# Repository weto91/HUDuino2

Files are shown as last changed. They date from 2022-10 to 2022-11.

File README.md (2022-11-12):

This project is under development. at this point everything is working, but there are some design issues that needs to be fixed. You can see the next steps below.

------------

### Next steps:
 - [ ] Add video of operation in README.md.
 - [ ] Redesign the shell to better fit any full-face helmet
 - [ ] Fix the problems that arise in the code.
 - [ ] Modify the wiring diagram to use the development board wemos d1 mini instead of nodemcu ESP12

------------

##  Description
HUDuino is an implementation of a HUD for bikers. This HUD will allows the biker to visualize the speed at which they are driving, the temperature inside the helmet, as well as the humidity, and they will be able to see if any notifications arrive on the phone while they are driving. 
This project seeks to improve the safety of bikers, avoiding distractions by lowering the head or handling the phone. 
Here you will find all the necessary resources to: 
 
 - View or modify the source code of the Android application
  - View, modify and upload to the development board the code necessary to make it work 
  - Make the electronic connections on the development board. 
  - Build the case for all the hardware with a 3D printer.

This project has three parts:
 - Android application
 - Arduino Sketch
 - Hardware construction

##  Android application 
The application will obtain several telemetries (described below) and send them via bluetooth to the Arduino device. It will also receive temperature and humidity data from the Arduino device.
The telemetry obtained by the application are:
- GPS Speed (Using Google API)
- Notifications received on the phone (It will only show that you have a notification from a specific application) The applications considered for notifications are the following:
   - WhatsApp
   - Facebook (and Facebook Messenger)
   - Instagram
   - Incoming calls (Considers the official android and samsung call application. Other applications of other brands are not contemplated, below it will be described how to add them)
   - The rest of the notifications will be ignored (Although they can be shown by modifying a bit of code)

##  Arduino Sketch

The Sketch is prepared to be used with the following components:
- ESP8266, any one will do, but so that it takes up as little space as possible and can fit in the case I have designed, it will have to be a Wemos D1 mini (or a replica)
- 0.96 inch I2C OLED screen. Any will do, but I recommend white or blue for better visibility.
- DHT22 temperature sensor, in this project the version with circuit is used, since it includes the resistance that the sensor needs to work correctly. However, we must eliminate the plastic that covers the sensor, thus saving space.
- HC-06 bluetooth module. The HC-05 model would also work, but to reduce costs and simplify the code, this model has been chosen.
- TC4056A, to charge the battery. I have chosen this model because it allows you to charge the battery while using the product, it also takes up very little space and is easy to use. It has USB-C.
- HAC-006 battery. It is the one used in the Nintendo Switch joycons. I have chosen this one because of its small size, durability and because it is cheap on amazon.
- The cables must be fine. CAT-5 network cables or AWG24 electrical cable can be used.
- A mirror sticker will also be needed
- And finally, a reflective protector

I will leave links to all the necessary hardware below, in "links"
### How its works:
The sketch repeats its operation every 0.1 seconds. It listens for SoftwareSerial (Bluetooth). It makes a cut of what is received, making sure to get only 3 characters for each reception, according to the received characters, through control structures, it will do different actions:
- Switch between KM/h and mph
- Show GPS speed
- Warn if any notification arrives

In addition, it will continuously read the DHT-22 sensor, display the humidity and temperature values on the screen and send them via SoftwareSerial to the smartphone.

 ##  3D case
 The case has been designed with SolidWorks. The editable SLDPRT files are attached, as well as the STL if you want to print them directly.

They are prepared to house all the components, wiring everything in the tightest way possible so that the whole occupies as little as possible inside the helmet.

Please note that this part is still under development. Soon I will be uploading the updated designs so that it fits better inside any helmet.
 ##  Wiring
 Use this diagram to wire your own HUDuino:
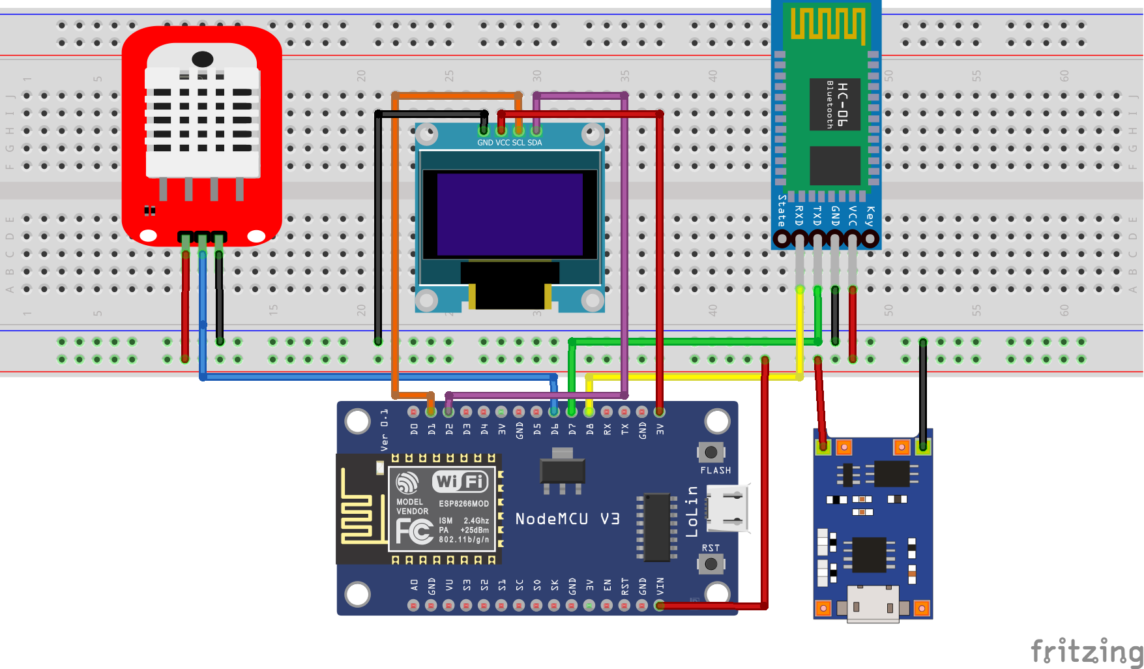
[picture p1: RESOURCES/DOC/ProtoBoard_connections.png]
 
| ESP8266 PIN | Component PIN  |
|--|--|
| D8 | RXD Bluetooth |
| D7 | TXD Bluetooth |
| D6 | Signal DHT22 |
| D2 | SDA Display |
| D1 | SCL/SCK Display |
| 3V3 | VCC Display |
| VIN | VCC DHT22 |
| VIN | VCC Bluetooth |
| VIN | + TC4056A |

 ##  Links

Aliexpress:
- [Wemos D1 Mini V3.0 (3,54€)](https://es.aliexpress.com/item/1005001621784437.html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)
- [0,96 inch OLED SSD1306 (2,37€)](https://es.aliexpress.com/item/4001028369082.html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)
- [DHT-22 with PCB (2,46€)](https://es.aliexpress.com/item/33037061522.html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)
- [HC-06 compatible (2,65€)](https://es.aliexpress.com/item/1005004472598061.html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)
- [TC4056A USB-C (1,85€)](https://es.aliexpress.com/item/1005002925698704.html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)
- [Mirror sticker 10u (1,37€)](https://es.aliexpress.com/item/1005004340986514.html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)
- [reflective sticker (1,83€)](https://es.aliexpress.com/item/1005002937614641.html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)
- [AWG24 wire 5M (2€)](https://es.aliexpress.com/item/1005003164183920.html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)

**Total cost: 18,07€**

Amazon:
- [Wemos D1 Mini V3.0 (6,49€)](https://www.amazon.es/AZDelivery-D1-Mini-desarrollo-compatible/dp/B01N9RXGHY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,aps,95&sr=8-3&th=1)
- [0,96 inch OLED SSD1306 (8,99€)](https://www.amazon.es/dp/B01L9GC470/ref=twister_B082M8VWLT?_encoding=UTF8&psc=1)
- [DHT-22 with PCB (8,99€)](https://www.amazon.es/temperatura-humedad-Arduino-Raspberry-AZDelivery/dp/B078SVZB1X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,aps,107&sr=8-5)
- [HC-06 compatible (9,99€)](https://www.amazon.es/dp/B0722MD4FY/ref=twister_B082KJ7KD5?_encoding=UTF8&psc=1)
- [TC4056A Micro-USB (4,49€)](https://www.amazon.es/AZDelivery-TP4056-Micro-Laderegler-Lithium/dp/B089QJZ3QP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)
- [Mirror sticker 10u (6,99€)](https://www.amazon.es/gp/product/B09B7799BC/ref=ppx_yo_dt_b_asin_title_o03_s00?ie=UTF8&psc=1)
- [reflective sticker 2u (10,99€)](https://www.amazon.es/Hud-Pel%C3%ADcula-reflectante-parabrisas-unidades/dp/B09TK36C1N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)
- [AWG24 wire 60M (13,90€)](https://www.amazon.es/Velleman-MOWM-60m-Cable-se%C3%B1al/dp/B001IRVDV4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)

**Total cost: 70,83€**

(Obviously it is better to wait for aliexpress)

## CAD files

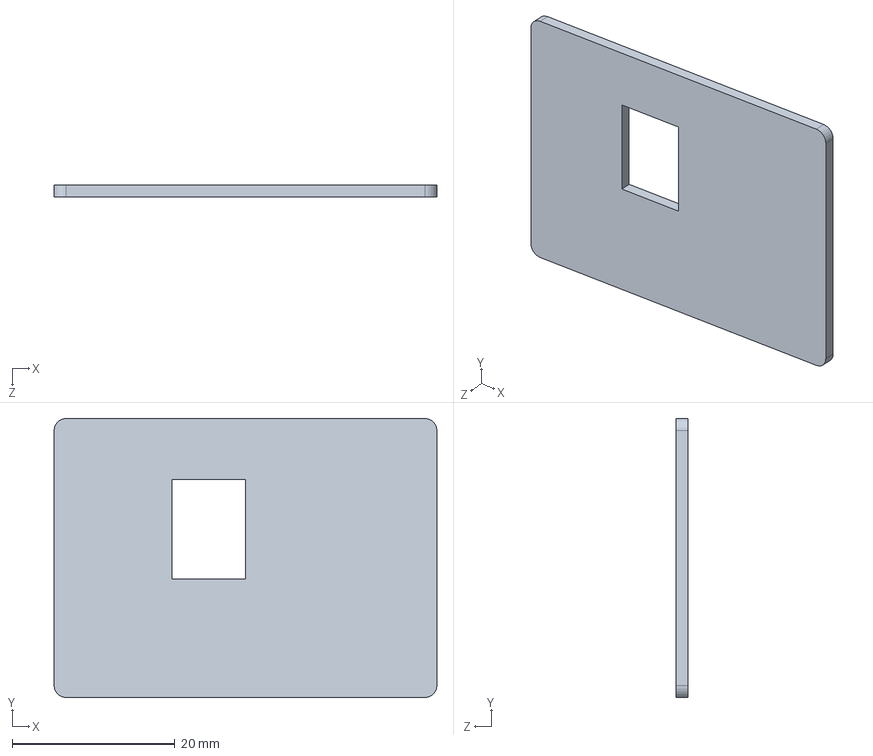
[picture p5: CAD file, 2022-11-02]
RESOURCES/SHIELD_3D/SLDPRT/HUDuino_med_V0_1.SLDPRT
47.0 x 34.2 x 1.50 mm

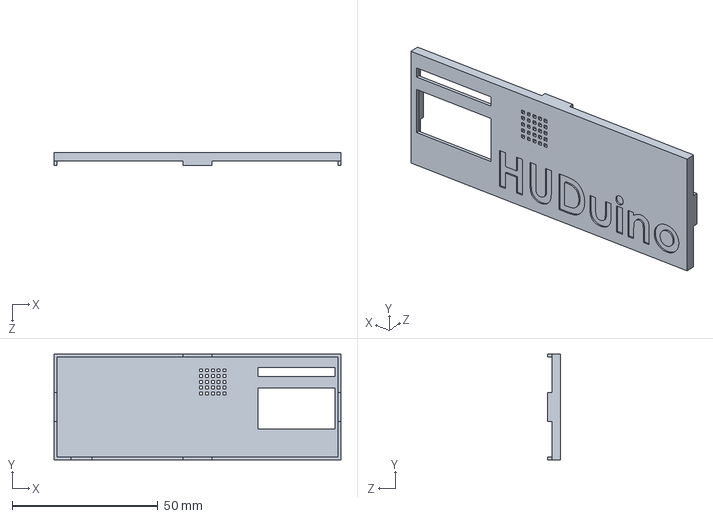
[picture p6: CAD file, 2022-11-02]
RESOURCES/SHIELD_3D/SLDPRT/HUDuino_top_V0_1.SLDPRT
98.5 x 36.2 x 4.50 mm

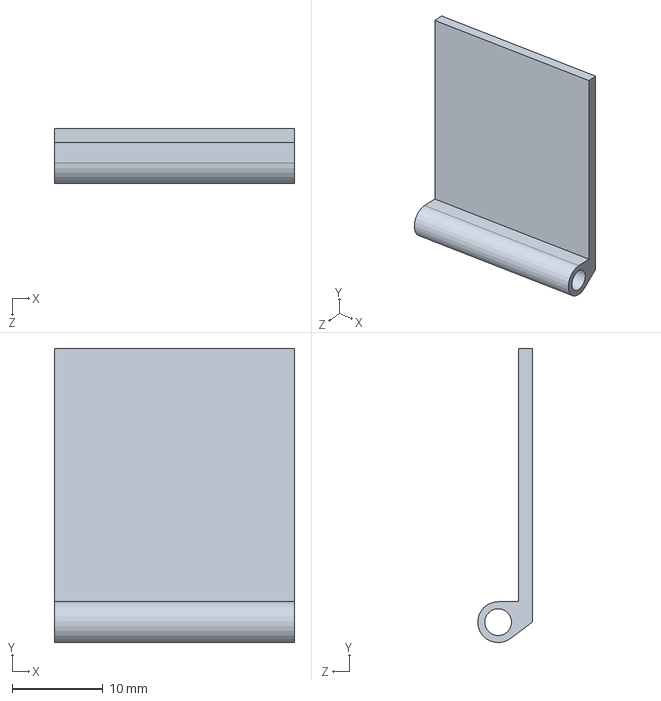
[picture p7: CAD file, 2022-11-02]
RESOURCES/SHIELD_3D/SLDPRT/HUDuino_scr_V0_1.SLDPRT
26.4 x 32.3 x 6.00 mm

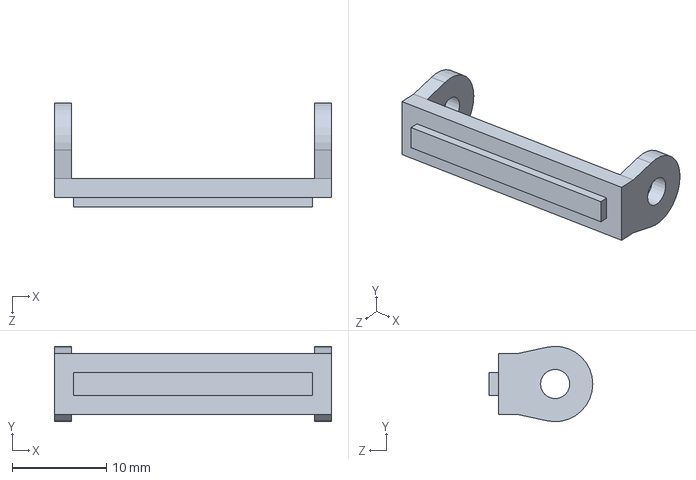
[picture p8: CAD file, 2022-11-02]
RESOURCES/SHIELD_3D/SLDPRT/HUDuino_sup_V0_1.SLDPRT
29.4 x 7.99 x 11.0 mm

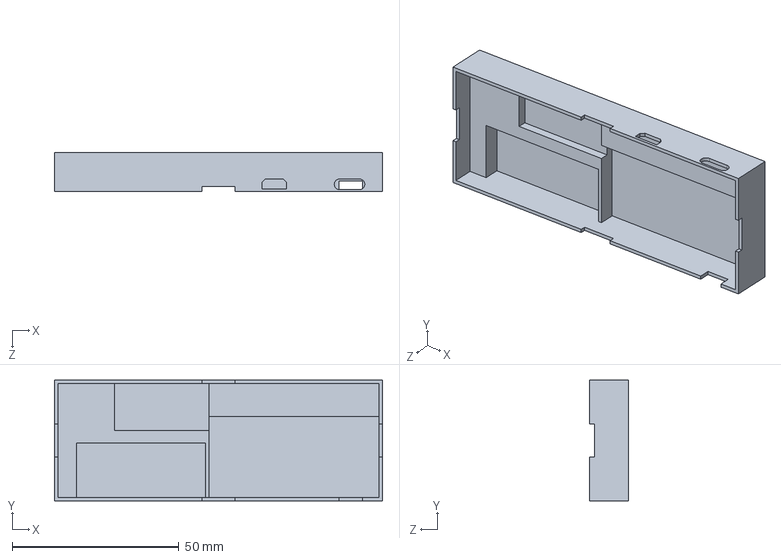
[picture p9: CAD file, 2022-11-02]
RESOURCES/SHIELD_3D/SLDPRT/HUDuino_base_V0_1.SLDPRT
98.5 x 36.2 x 11.8 mm

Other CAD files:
RESOURCES/SHIELD_3D/STL/HUDuino_base_V0_1.STL
RESOURCES/SHIELD_3D/STL/HUDuino_med_V0_1.STL
RESOURCES/SHIELD_3D/STL/HUDuino_scr_V0_1.STL
RESOURCES/SHIELD_3D/STL/HUDuino_sup_V0_1.STL
RESOURCES/SHIELD_3D/STL/HUDuino_top_V0_1.STL

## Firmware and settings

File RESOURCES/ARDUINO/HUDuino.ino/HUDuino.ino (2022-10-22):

#include <SoftwareSerial.h>    //For bluetooth communication
#include <Wire.h>              //This library allow the I2C communication
#include <Adafruit_GFX.h>      //Graphics for the screen
#include <Adafruit_SSD1306.h>  //Screen driver
#include <DHT.h>               //DHT-22 Library

#define SCREEN_WIDTH 128  // OLED display width, in pixels
#define SCREEN_HEIGHT 64  // OLED display height, in pixels
#define DHTPIN 12         // GPIO PIN
#define DHTTYPE DHT22     //DHT TYPE (DHT11, DHT22...)

DHT sensor(DHTPIN, DHTTYPE);
Adafruit_SSD1306 display(SCREEN_WIDTH, SCREEN_HEIGHT, &Wire, -1);
SoftwareSerial hc06(13, 15);  //Serial for BT : Rx/Tx pin

//Useful variables
String cmd, data, notification = "";
String speed = "  0";
String speedUnit = " kmh/h";
String temperatureUnit = " C";
int sensor_val = 0;
int humidity, temperature = 0;
int lastRead = 0;
int waitDHT22 = 2000;
//START the application
void setup() {
  Serial.begin(9600);  //Initialize Serial Monitor
  hc06.begin(9600);    //Initialize Bluetooth Serial Port
  sensor.begin();      //Initialize DHT-22 sensor
  if (!display.begin(SSD1306_SWITCHCAPVCC, 0x3C)) {
    Serial.println(F("SSD1306 allocation failed"));
    for (;;)
      ;
  }
  delay(2000);
  display.clearDisplay();                          //Clear everything in the display
  display.setTextSize(1);                          //Font size small
  display.setTextColor(WHITE);                     //Color must be white, this screen have not any other color.
  display.setCursor(0, 10);                        //Positions: x,y
  display.println("Please, connect your phone.");  // print text in the screen
  display.display();                               //Refresh data and show everything
}

void loop() {
  if (lastRead > waitDHT22) {                       //Readings should be made every two seconds, not before
    humidity = round(sensor.readHumidity());        //Obtain temperature from DHT-22 and round to int
    temperature = round(sensor.readTemperature());  //Obtain humidity from DHT-22 and round to int
    if (isnan(temperature) || isnan(humidity)) {    //Check if the DHT-22 is failing.
      Serial.println("Error reading values of DHT22");
      lastRead = 0;
      return;
      temperature = 0;
      humidity = 0;
    }
    lastRead = 0;
  }
  //Read data from HC06 when BT connection is available.
  while (hc06.available() > 0) cmd += (char)hc06.read();

  //Trim the obtained data from BT to 3 characters (BT can be very dirty)
  if (cmd != "") {
    if (cmd.length() > 3) data = cmd.substring(0, 3);
    else if (cmd.length() == 3) data = cmd;
    else if (cmd.length() == 2) data = " " + cmd;
    else if (cmd.length() == 1) data = "  " + cmd;

    //Check if data received is any notification
    if (data == "FBK") notification = "Facebook notification";
    else if (data == "IGM") notification = "Instagram notification";
    else if (data == "WSP") notification = "Whatsapp notification";
    else if (data == "ICL") notification = "In-call notification";
    else if (data == "OTR") notification = "Other notification";
    else if (data == "RSN") notification = "";

    //Check if data received is the SPEED
    if (isDigit(data.charAt(2))) speed = data;

    //Check if data received is the speed units change
    if (data == "0ME") speedUnit = " km/h";
    else if (data == "0IM") speedUnit = " mph";

    display.clearDisplay();  //CLEAR SCREEN
    //HUMIDITY
    display.setTextSize(1);
    display.setCursor(0, 0);
    display.println(String(humidity) + " %");
    //TEMPERATURE
    display.setTextSize(1);
    display.setCursor(100, 0);
    display.println(String(temperature) + temperatureUnit);
    //SPEED
    display.setTextSize(3);
    display.setTextColor(WHITE);
    display.setCursor(25, 20);
    display.println(speed);
    //SPEED UNIT
    display.setTextSize(1);
    display.setTextColor(WHITE);
    display.setCursor(75, 34);
    display.println(speedUnit);
    //NOTIFICATIONS
    display.setTextSize(1);
    display.setCursor(0, 57);
    display.println(notification);

    display.display();  // PRINT SCREEN
    cmd = "";           //reset cmd
    data = "";
  }
  //Write sensor data to HC06
  hc06.print(temperature);
  delay(100);
  lastRead += 100;  //This is for the while
}

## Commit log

2022-10-19 - Added new languages - Added new button to restart notifications alerts - Fixed some things
2022-10-19 - Screen view defined - Received speed and notifications - Text sizes defined - improve received data to 3 chars (bacause there is a little bluetooth noise)
    [HUDuino.ino]
2022-10-22 - Added the first data sended to arduino (This is because the arduino shows message until android send the data) - Added DHT-22 to arduino - Added new textView to show humidity - Some visual fixes - 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
    [HUDuino.ino]
2022-10-23 - Move files to RESOURCES folder - Add SolidWorks parts - Add STL parts - Add eschematic connections in protoboard
    [HUDuino_base_V1_0.SLDPRT, HUDuino_base_V1_0.STL, HUDuino_top_V1_0.SLDPRT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]
2022-11-02 - New shell for electronic parts.
    [HUDuino_base_V0_1.SLDPRT, HUDuino_base_V0_1.STL, HUDuino_base_V1_0.SLDPRT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]
